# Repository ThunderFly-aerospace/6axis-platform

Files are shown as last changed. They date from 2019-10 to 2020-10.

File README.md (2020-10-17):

# Takeoff and landing car roof platform

6 axis pneumatic cilinders based platform used for UAV transport and in field depoyment.  It is mounted on the roof on the car and has capability to carry and launch UAV mounted on it.

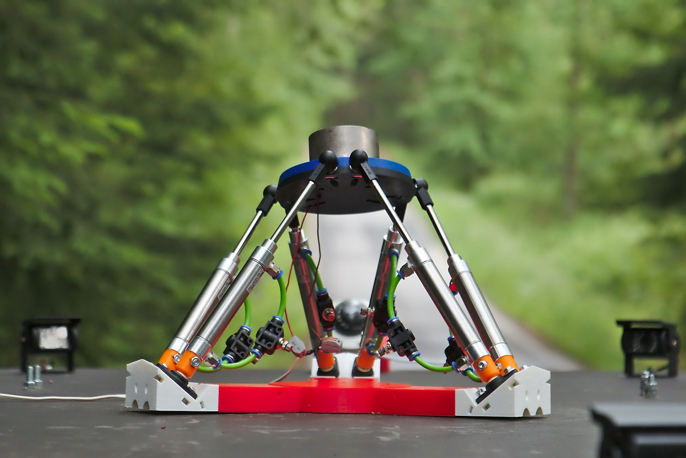
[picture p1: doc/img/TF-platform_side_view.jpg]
ThunderFly 6-axis UAV testing platform


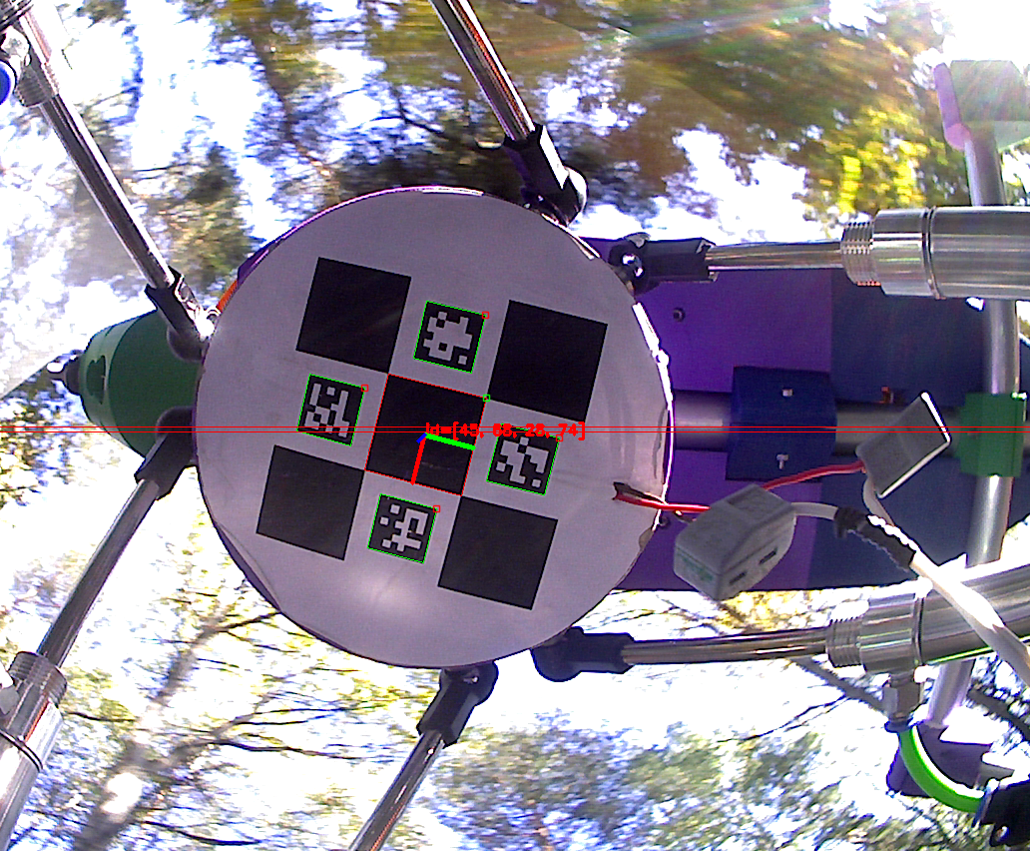
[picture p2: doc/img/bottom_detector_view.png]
position estimation Charuco diamond on bottom of platform


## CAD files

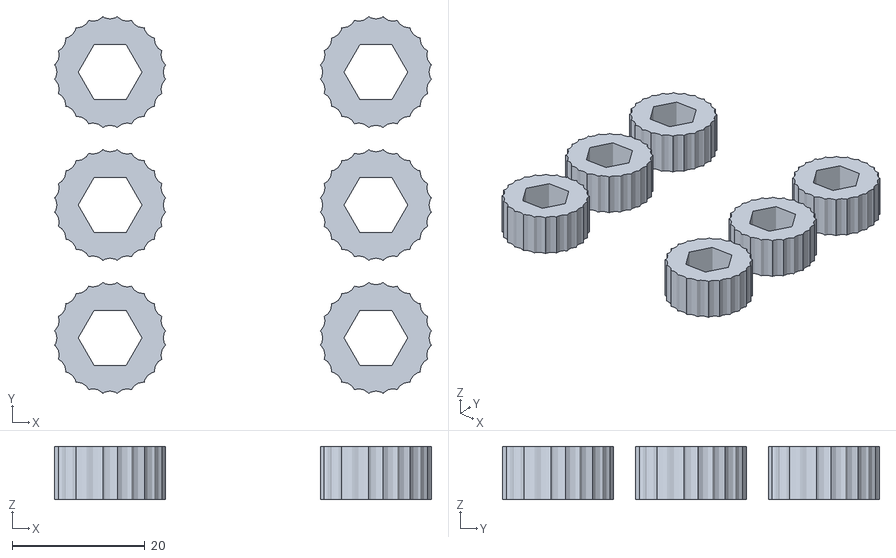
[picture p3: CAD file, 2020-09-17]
CAD/stl/printplate_888_4007.stl
56.7 x 56.7 x 8.00

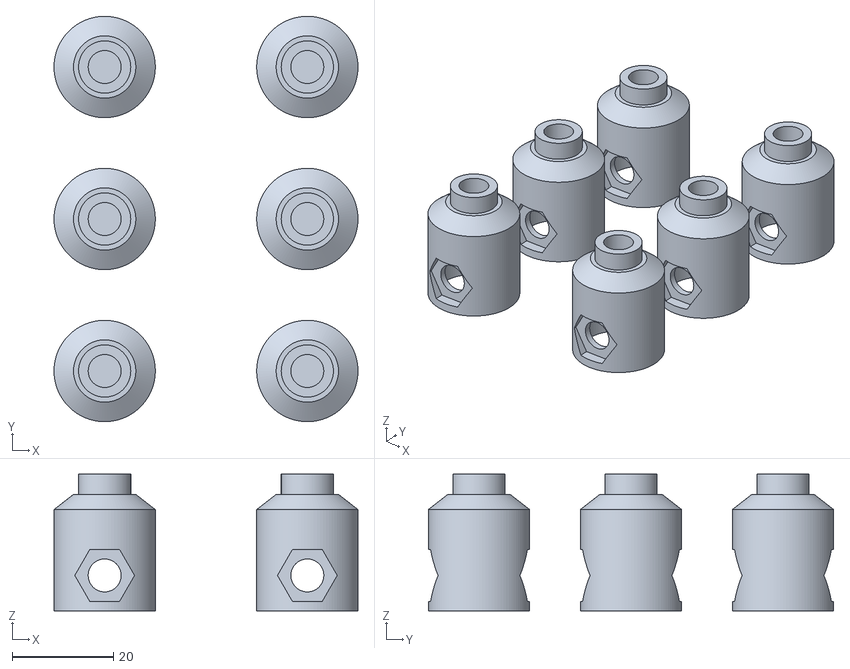
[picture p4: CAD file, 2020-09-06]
CAD/stl/printplate_888_4002.stl
60.0 x 80.0 x 27.0

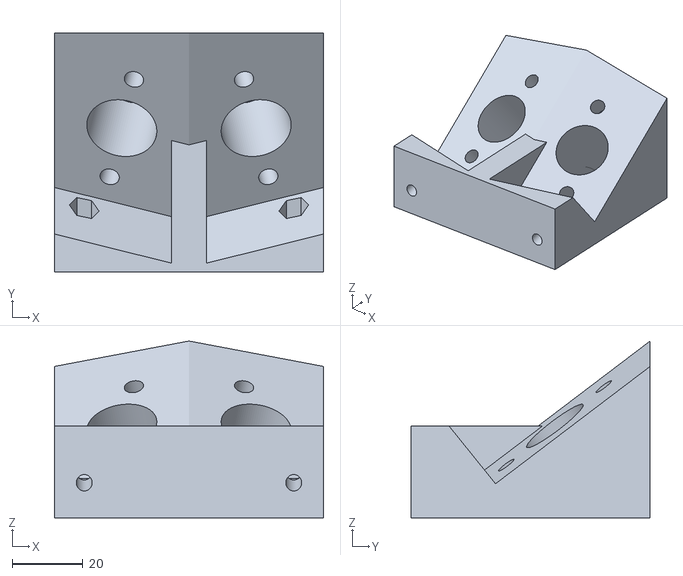
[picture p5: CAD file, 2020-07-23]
CAD/stl/printplate_888_4003.stl
76.0 x 67.6 x 50.0

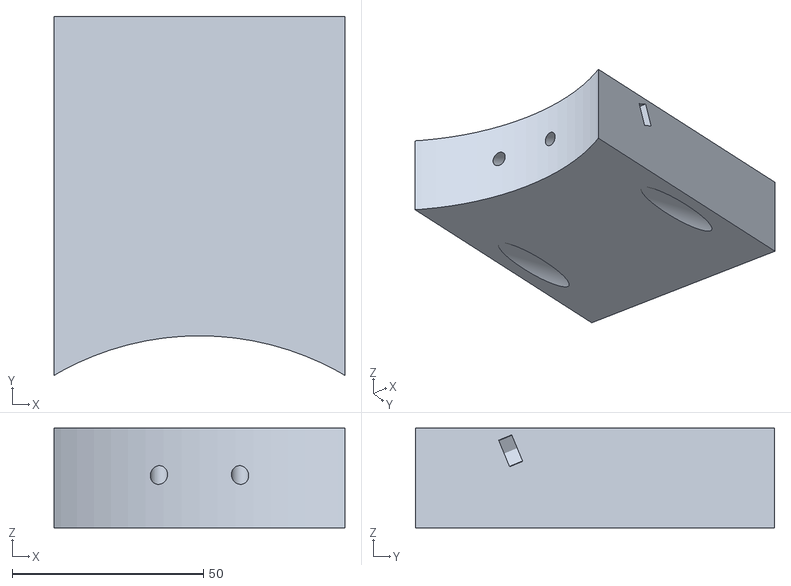
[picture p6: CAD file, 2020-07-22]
CAD/stl/printplate_888_4006.stl
76.0 x 93.8 x 26.0

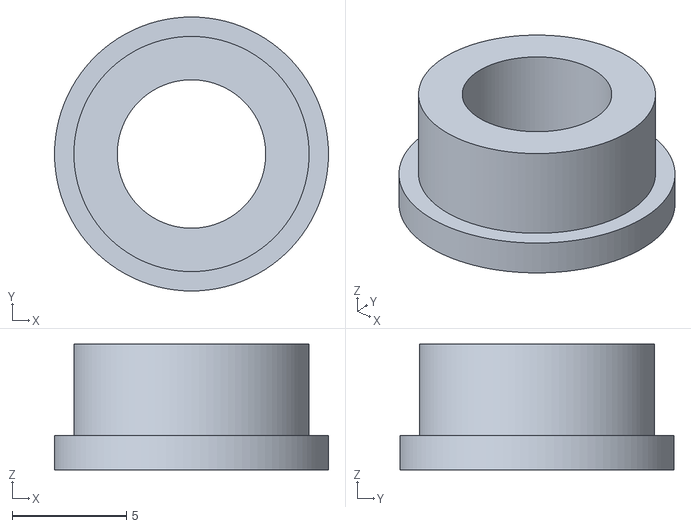
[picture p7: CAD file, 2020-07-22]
CAD/stl/printplate_888_4001.stl
12.0 x 12.0 x 5.50

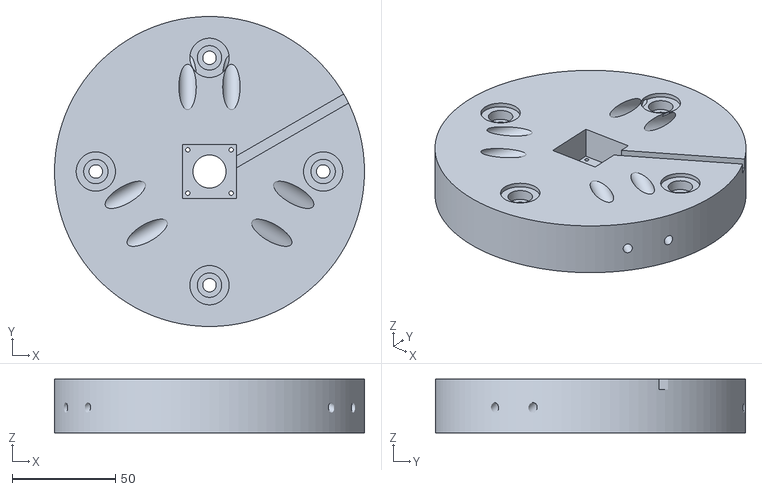
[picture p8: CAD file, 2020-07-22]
CAD/stl/printplate_888_4004.stl
150.0 x 150.0 x 26.0

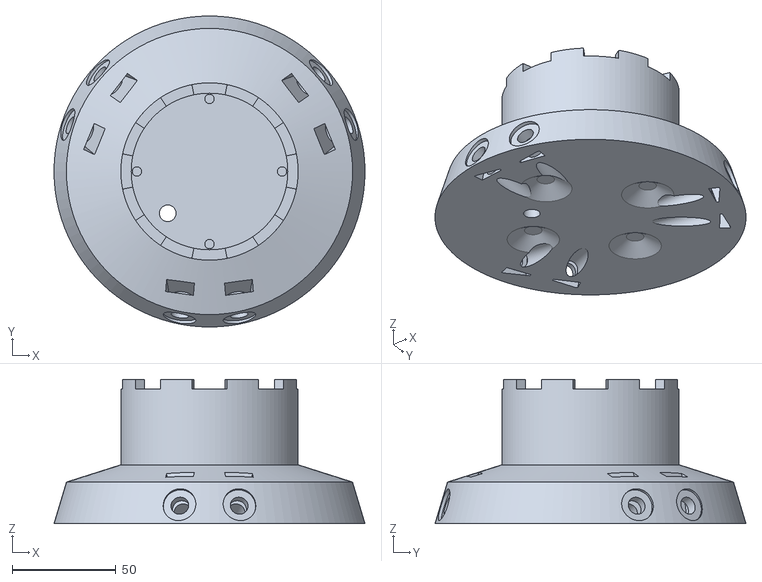
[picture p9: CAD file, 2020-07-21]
CAD/stl/printplate_888_4005.stl
150.0 x 150.0 x 69.5

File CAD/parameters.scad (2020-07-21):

include <../parameters.scad>

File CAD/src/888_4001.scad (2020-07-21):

//prumer loziska 10 mm
//pocinato se sroubem M8 o min delce 20 mm

include <../../parameters.scad>
inner_diameter = M6_screw_diameter;
rim_outer_diameter=12;
rim_height = 1.5;

module 888_4001(draft = true){

    difference(){
        union(){
            cylinder(h = rim_height, d = rim_outer_diameter, $fn = 100);
            translate([0,0,rim_height])
                cylinder(h = (bearing_EFOM_10_h/2)-0.5, d = bearing_EFOM_10_d1, $fn = 100);
        }
        cylinder(h = 2 * bearing_EFOM_10_h , d = inner_diameter, $fn = 100);
    }
}
888_4001();

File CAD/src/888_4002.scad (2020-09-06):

include <../../parameters.scad>
//sroub pro propojení pistu k 3D vytisku je M6
//dno je tluste 3 mm
//sroub pro prřipojení 3D vytisku k lozisku je M6, hlava soubu je ulozena  blize k pistu.


module 888_4002(){
  piston_thread_height=13+1;
  connecting_height=piston_thread_height+M6_head_height;
  //velikost vnejsiho prumeru soucastky
  connecting_diameter=20;
  piston_thread_diameter=16+0.2;
  //seriznuti valce
  piston_cutout=12.1;
  bearing_ball_height=bearing_EFOM_10_h-0.8;
  bottom_height=3;
  hole_pozition=7;//posunuti diry pro pripevneni vytisku k pistu měřeno od širší části.
  insert_nut_connecting_pozition = connecting_height-hole_pozition+bottom_height;

  difference(){
      //cast ktera se pripevni na pist
      union(){
          translate([0,0,bottom_height])
              cylinder(h=connecting_height,d=connecting_diameter,$fn=100);
          cylinder(h=bottom_height, d1 = bearing_EFOM_10_d1+2, d2 = connecting_diameter, $fn=100);   //zkoseni dna

          //cast ktera prochazi kulovym loziskem
          translate([0,0,-((bearing_EFOM_10_h/2)-global_clearance)])
              cylinder(h=(bearing_EFOM_10_h/2)-global_clearance,d=bearing_EFOM_10_d1,$fn=100);
      }

      //vyrez pro nasazeni
      difference(){
           translate([0,0,bottom_height+M6_head_height])
              cylinder(h=piston_thread_height + global_clearance,d=piston_thread_diameter,$fn=100);

          translate([0,piston_cutout/2+5/2,bottom_height+M6_head_height+piston_thread_height/2])
              cube([piston_thread_diameter,5,piston_thread_height],center=true);
          translate([0,-piston_cutout/2-5/2,bottom_height+M6_head_height+piston_thread_height/2])
              cube([piston_thread_diameter,5,piston_thread_height],center=true);
      }
      //vyrez pro ulozeni hlavy sroubu M6 do dna
      translate([0,0,bottom_height])
          //cylinder(h=M6_head_height, d=M6_nut_diameter,$fn=6);
          cylinder(h=M6_head_height - layer_thickness, d=M6_nut_diameter,$fn=6);



      //pruchod pro sroub (zaslepeny kvuli tisku)
      translate([0,0,-((bearing_EFOM_10_h/2)-global_clearance)])
          cylinder(h=(bearing_EFOM_10_h/2)-global_clearance + bottom_height - layer_thickness, d=M6_screw_diameter,$fn=100);


      //otvor pro pripevneni na pist pomoci sroubu
      rotate([90,0,0]){
          translate([0,insert_nut_connecting_pozition,0])
              cylinder(h=connecting_diameter,d=M6_screw_diameter,$fn=100,center=true);
      //sestihran pro zapusteni matky pri montazi
          translate([0,insert_nut_connecting_pozition,connecting_diameter/2-M6_nut_height/2])
              cylinder(h=M6_nut_height/2,d=M6_nut_diameter,$fn=6);
          translate([0,insert_nut_connecting_pozition,-connecting_diameter/2])
              cylinder(h=M6_nut_height/2,d=M6_nut_diameter,$fn=6);
      }
  }
  //zaslepka pro tisk
  /*translate([0,0,bottom_height])
    cylinder(h=layer_thickness,d=connecting_diameter);
*/
}

difference(){
  888_4002();
  translate([0,0,-50]) cube(100);

}

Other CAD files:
CAD/src/888_4003.scad
CAD/amf/printplate_888_4001.amf
CAD/amf/printplate_888_4002.amf
CAD/amf/printplate_888_4003.amf
CAD/amf/printplate_888_4004.amf
CAD/amf/printplate_888_4005.amf
CAD/amf/printplate_888_4006.amf
CAD/amf/printplate_888_4007.amf
CAD/src/888_4004.scad
CAD/src/888_4005.scad
CAD/src/888_4006.scad
CAD/src/888_4007.scad
CAD/src/assembly.scad
CAD/src/calculations.scad
CAD/src/printplate/printplate_888_4001.scad
CAD/src/printplate/printplate_888_4002.scad
CAD/src/printplate/printplate_888_4003.scad
CAD/src/printplate/printplate_888_4004.scad
CAD/src/printplate/printplate_888_4005.scad
CAD/src/printplate/printplate_888_4006.scad
CAD/src/printplate/printplate_888_4007.scad
parameters.scad

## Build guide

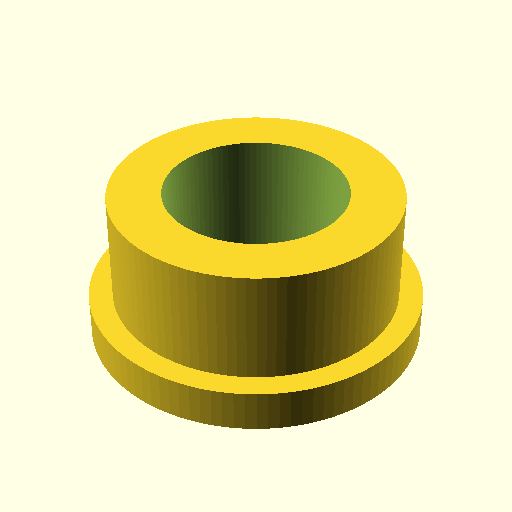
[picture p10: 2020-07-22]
CAD/png/printplate_888_4001.png

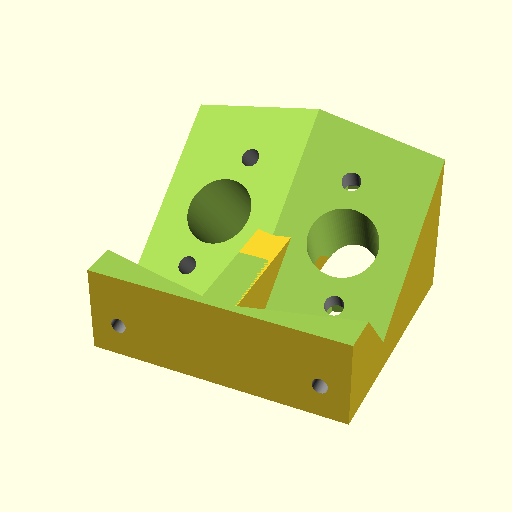
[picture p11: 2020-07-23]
CAD/png/printplate_888_4003.png

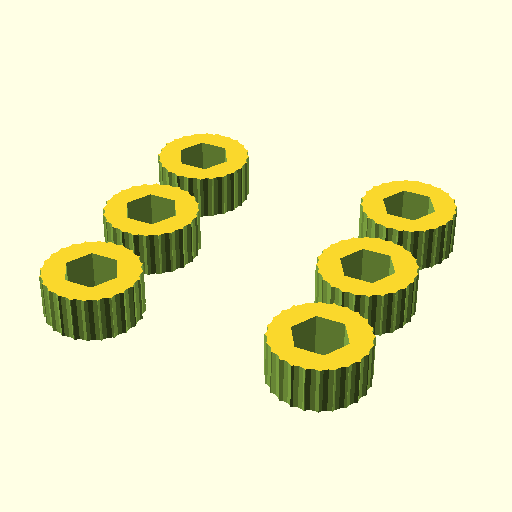
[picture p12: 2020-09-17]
CAD/png/printplate_888_4007.png

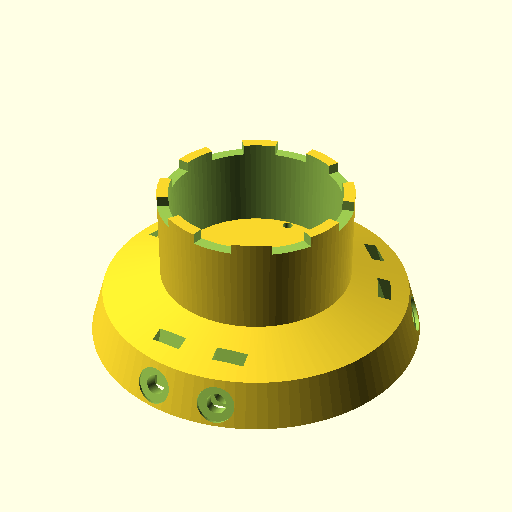
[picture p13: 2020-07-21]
CAD/png/printplate_888_4005.png

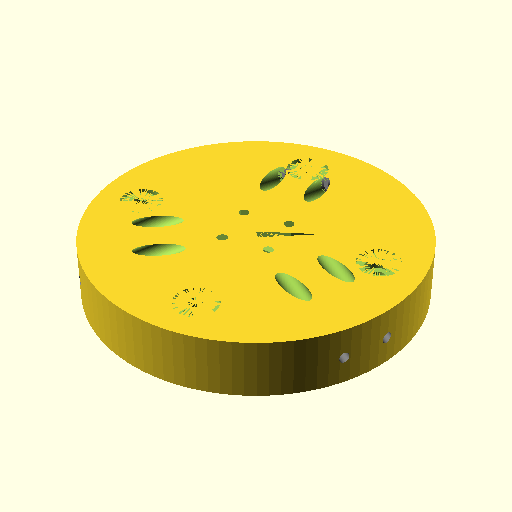
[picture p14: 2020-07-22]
CAD/png/printplate_888_4004.png

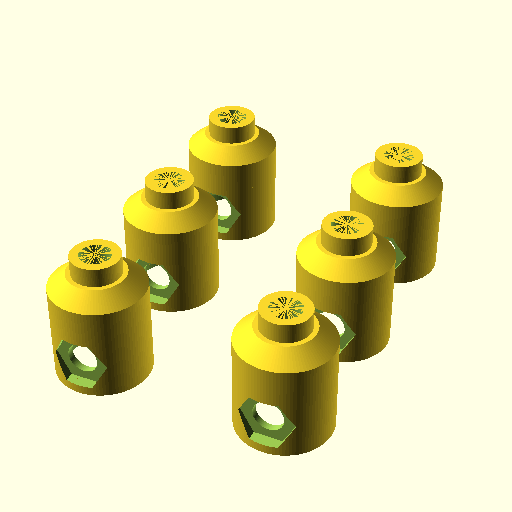
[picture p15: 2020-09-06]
CAD/png/printplate_888_4002.png

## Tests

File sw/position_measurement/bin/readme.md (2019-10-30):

# Utilities for detection of charuco markers at bottom of platform 

    ./detect_diamonds -c="../data/calib_DMM-1118.txt" -dp="../data/detector_params.yml" -sl=0.0305 -ml=0.0185 -d=10

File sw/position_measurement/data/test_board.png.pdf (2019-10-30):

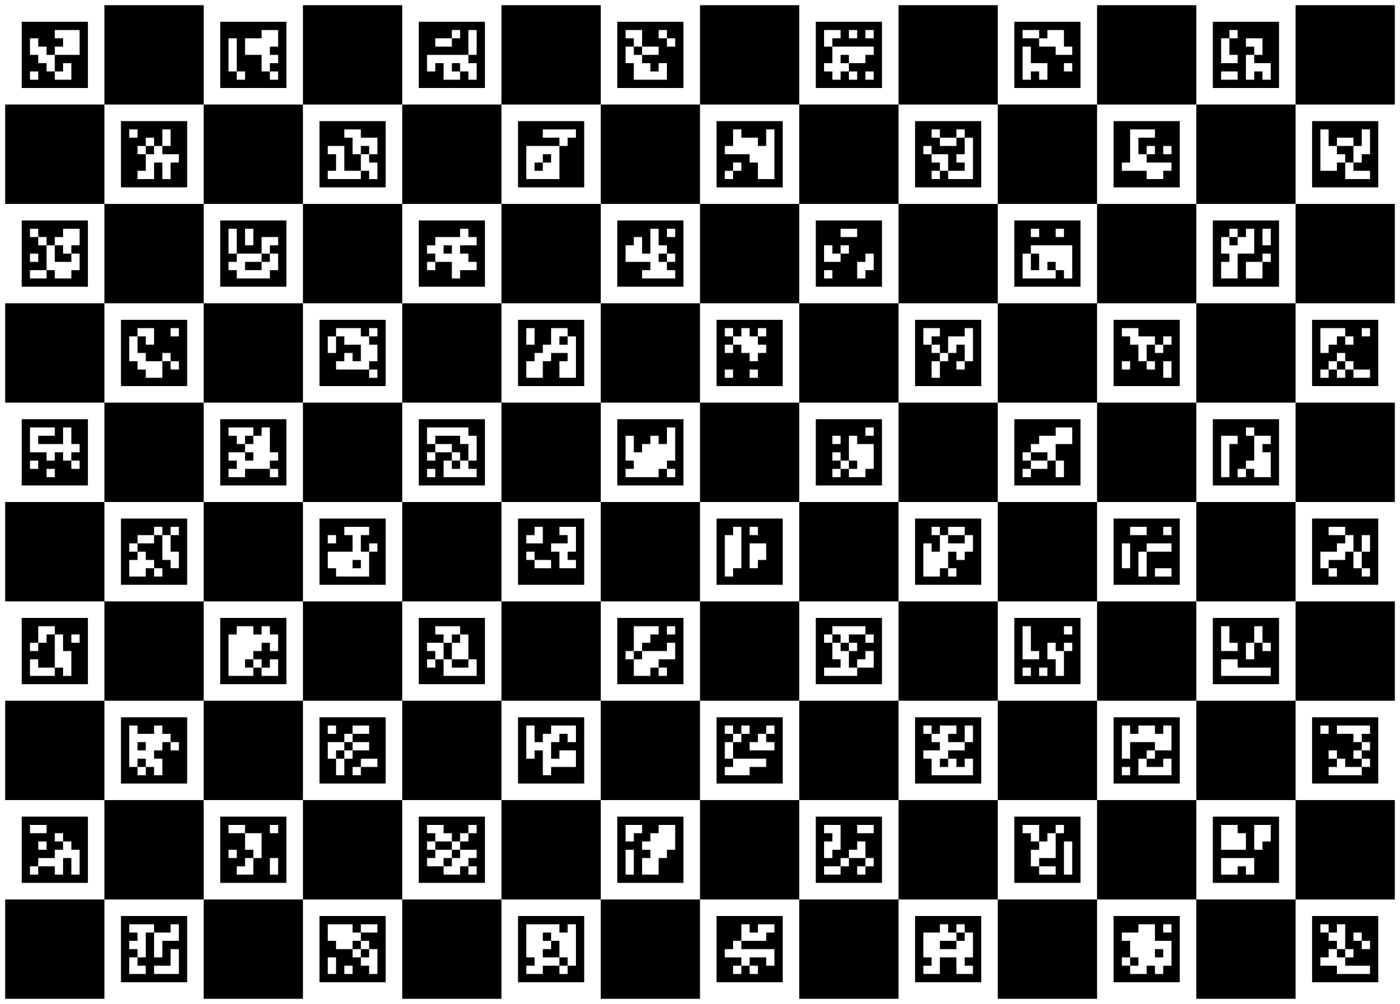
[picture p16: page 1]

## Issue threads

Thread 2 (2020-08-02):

Tisknutelnost dílu patky pístu

kaklik, 2020-08-02:
Díl je nyní tištěn na širší část, kdy je strana do které se vkládá pístnice položena na tiskovou podložku.
Tato tisková orientace je v pořádku. Není však na to připraven model, protože nebsahuje mostovací vrstvy, které by umožnily kvalitní vytištění šestihranu pro hlavu šroubu.

kaklik, 2020-09-06:
Tak z tohodle víceméně banálního issue, se stala celkem prekérní záležitost.
Zjistil jsem totiž, že když přidám jednu mostovací vrstu, tak aby model vypadal v řezu takhle (zobrazeno v pozici pro tisk):

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

Tak slic3r začne ignorovat dutý prostor mezi oběma plnými vrstvami (šestihranný prostor pro hlavu šroubu).

Toto chování je vidět na g-kódu, kde tento obrázek je vygenerován z modelu, který nejspodnější mostovací vrstvu neobsahuje (šestihran pro hlavu šroubu je vyslicován):

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

Tento model mostovací vrstvu obsahuje a šestihran je ignorován:

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

Když se odebere vrchní mostovací vrstva, takto:

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

Tak slic3r vnitřní šestihran vygeneruje i včetně spodní mostovací vrstvy. Jednotlivé mostovací vrstvy jsou tak namodelovány správně.

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

Slic3r (Slic3r 1.3.1-dev (Build 6eeea77) on 2020-09-06 at 22:57:31) tedy ignoruje vnitřní uzavřené objemy.

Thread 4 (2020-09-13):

Knoflík pro ovládání ventilů platformy

kaklik, 2020-09-13:
Platforma má nové škrtící ventily, které mají nastavovací šroub se šestihranou hlavou.
Hlava je vysoká 8mm a vrcholy 6tihranu jsou na průměru 9.05mm. K ovládání se běžně používá klíč velikosti 8mm.

Při vytvoření ovládacího knoflíku lze vyjít z konstrukce: https://github.com/UniversalScientificTechnologies/MLAB-3Dprinter/blob/multimotor/hw/cad/src/4printing/heatbed-nut.scad

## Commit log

2019-10-30 Initial commit of position measurement samples based on charuco diamonds.
2019-12-15 Commiting of files from TF-R1 repository.
    [888_4001.scad, 888_4002.scad, 888_4003.scad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]
2020-07-20 Oprava otočení vývodu pro vodiče. Zlepšení natočení pro tisk Zrušení offsetu oproti středu platformy.
    [888_4005.scad]
2020-07-20 Adding locking mechanism for magnet
    [888_4005.scad]
2020-07-20 Adding clearence
    [888_4005.scad]
2020-07-21 Locking teeth repair
    [888_4005.scad]
2020-07-21 Úpravy chyb a roznesení hmotnosti v platformě.
    [888_4005.scad, calculations.scad]
2020-07-21 Adding vertical gap for locking mechanism
    [888_4005.scad]
2020-07-21 Printable files generation.
    [888_4005.scad, printplate_888_4005.amf, printplate_888_4005.scad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]
2020-07-21 Printable files generation aid.
2020-07-21 Increasing of clearances.
    [888_4003.scad, 888_4005.scad]
2020-07-21 Make printable set of components.
    [888_4001.scad, 888_4002.scad, 888_4003.scad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]
2020-07-22 Rendering of parts before printing 4005.gcode
    [printplate_888_4001.amf, printplate_888_4001.stl, printplate_888_4002.amf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]
2020-07-22 Decrease tolerance around magnet.
    [888_4005.scad, printplate_888_4005.amf, printplate_888_4005.stl]
2020-07-22 Restore connection of parts from @roman-dvorak
    [calculations.scad]
2020-07-22 Increase rigidity of beams by removing the nut pockets.
    [888_4003.scad, calculations.scad]
2020-07-22 Rendering and slicing before printing.
    [printplate_888_4002.amf, printplate_888_4003.amf, printplate_888_4003.stl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]
2020-07-23 Improve model printability.
    [888_4005.scad]
2020-07-23 Oprava průměru šroubů.
    [888_4003.scad, printplate_888_4003.amf, printplate_888_4003.stl]
2020-07-24 Increase layer thickness for faster printing.
    [printplate_888_4003.amf]
2020-09-06 Code cleanup before solving the issue: #2
    [888_4002.scad, printplate_888_4002.amf, printplate_888_4002.scad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]
2020-09-06 An attempt to solve. #2
    [888_4002.scad, printplate_888_4002.amf, printplate_888_4002.stl]
2020-09-16 The first version of pneumatic valve knob. #4
    [888_4007.scad, printplate_888_4007.amf, printplate_888_4007.scad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]
2020-09-16 Improve clearances.
    [888_4007.scad, printplate_888_4007.amf, printplate_888_4007.scad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]
2020-09-17 Roughly fix the clearance.
    [888_4007.scad, printplate_888_4007.amf, printplate_888_4007.stl]
2020-09-17 fine tunnig the clearance.
    [888_4007.scad, printplate_888_4007.amf, printplate_888_4007.stl]
